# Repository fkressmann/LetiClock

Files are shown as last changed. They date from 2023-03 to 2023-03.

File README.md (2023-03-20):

# LetiClock
German word clock implementation with some custom features. Maybe built for someone I like very much and maybe this 
explains the weird project name, maybe.

A demo of the full functionality (including OTA update) can be found 
[here on OneDrive](https://1drv.ms/v/s!ApTlIRJaAWv_hIA3SK2NMBU7i5G7rw?e=YNfXNx)

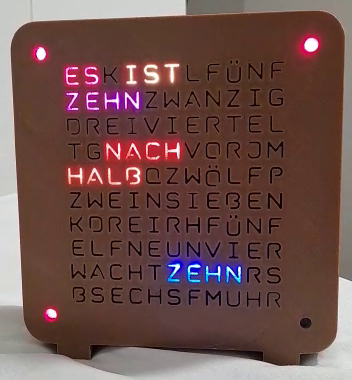
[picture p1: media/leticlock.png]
LetiClock


## Features
### Adaptive brightness with LDR
I put a LDR into the back side of the case and a voltage divider to read the environments' brightness.
Then an exponential function is used to account for the non-linearity of the sensor. The values were just the result of 
some experimentation.

### NTP sync
Time is synced with a given NTP server using the native time library.

### HTTP OTA Updates (incl simple PHP update server script and Dockerfile)
As the device is deployed in the field, I don't have physical access to it.
To still be able to push new features and fix bugs, it connects every few minutes to a predefined endpoint to check 
if a new firmware version is available.

The connection is encrypted over HTTPs, the certificate is self-signed and the fingerprint is part of the software 
configuration. The encryption was mainly done to encrypt MQTT traffic, and it would be pointless to maintain two 
WiFiClients.

The firmware server is a simple PHP script deployed in a docker container behind [Nginx Proxy Manager](https://nginxproxymanager.com/)
which handles the encryption. A small Python script is used to parse the version out of the C++ files and modify the PHP script.
Run configurations in IntelliJ (see .idea directory) are used to build the firmware, execute the Python script, build a container and deploy it
to my docker host. And yes, this can be massively improved, but it's more than sufficient for my needs.

### MQTT client for receiving scrolling text messages
C'mon on, that's fckin cool :D

Reasons for choosing MQTT were that 
- I already have a server that I maintain for my smart home devices 
- I didn't want to modify some firewalls in the place where it might be installed
- I wanted a way to send messages from whatever device

Implementation wise the interesting part is how messages are reliably delivered.
The secret there are the [QoS levels](https://www.hivemq.com/blog/mqtt-essentials-part-6-mqtt-quality-of-service-levels/)
of MQTT. 
The following requirements were set:
- A message should arrive even when network connection of the clock is bad
- A message should play until a user interaction
- A messages should not get lost because of a busy resource

I wanted to offload as much as I can to the broker. QoS level 1 helps a lot there,
as it guarantees a message to be delivered 'at least once'. So once my client first connects with QoS 1 and subscribes to a topic,
the broker will cache messages if the client goes offline / loses its connection.

And this can be used for queueing, too. Instead of keeping messages in memory, we query them one by one from the broker.
Once a message is received, the client disconnects from the broker and plays the
message until the user presses one of the two button on the backside. Further messages send during this time will be chaced
by the broker. Once the button was pressed, the clock goes back to normal mode, connects to the broker again and possibly receives the next message.
This goes on until all messages are processed.

### 3d print
As I could get my hands neither on 90 LED/m nor a 96 LED/m WS2812b, I went with a [100 LED/m WS2812 ECO](https://www.amazon.de/gp/product/B088JZCBDR) 
and scaled down the 90 LED/m 3D files X and Y axis to 90% in Cura. This worked out absolutely fine!

### Push button WiFi configuration
I figured out that WiFiManager opens the config portal in case it cannot connect to the last stored WiFi within a 
defined period of time. This is for the clocks use case unfortunate cause it's not often changing WiFi but used with 
flasky connections. So in the beginning it switched very often automatically to config mode.

To fix this, the config AP is activated by pressing both button on the back simultaneously. Otherwise, it will just indefinitely
try to connect to the last saved WiFi AP. This works perfect in the desired environment.

# Props
## Idea
- [3D Design | ingrimsch | WordClock 12h](https://www.thingiverse.com/thing:2130830)
- [Initial idea for the SW | mirohero | german word clock](https://github.com/mirohero/german-word-clock)
## Libraries
- [Scrolling Text lib | Aaron Liddiment | LEDMatrix / LEDText](https://github.com/AaronLiddiment)
- [FastLED | FastLED](https://github.com/FastLED/FastLED)
- [tzapu | WiFiManager](https://github.com/tzapu/WiFiManager)
- [knolleary | PubSubClient](https://github.com/knolleary/pubsubclient)

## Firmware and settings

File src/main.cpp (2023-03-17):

#include <Arduino.h>
#include <FastLED.h>
#include <LEDMatrix.h>
#include <LEDText.h>
#include <FontMatrise.h>
#include <time.h>
#include "ESP8266httpUpdate.h"
#include <DNSServer.h>
#include <WiFiManager.h>
#include <PubSubClient.h>
#include <credentials.h>

#define MY_NTP_SERVER "pool.ntp.org"
#define MY_TZ "CET-1CEST,M3.5.0/02,M10.5.0/03" // Settings for middle european time

#define VERSION     "LetiClock-v19"
#define LED_PIN     D3
#define LDR         A0
#define BUTTON_L    D1
#define BUTTON_R    D2
#define LED_TYPE    WS2812
#define COLOR_ORDER GRB

const String prefix = MQTT_PREFIX;
const char *topicMessage = "message";
const char *topicLog = "log";

void reconnectMqtt(boolean log);

void doBusiness();

struct {
    bool available = false;
    int length;
    char buffer[256];
} mqttMessage;

WiFiClientSecure espClient;
PubSubClient mqttClient(espClient);

cLEDMatrix<11, -10, HORIZONTAL_ZIGZAG_MATRIX> ledMatrix;
cLEDText ScrollingMsg;

int currentMinute, currentHour;
int previousMinute = 100; // Init with some insane value to trigger update on boot
const double E = 2.71828;
time_t now;
tm tm;
bool buttonL, buttonR = false;
bool outputEnabled = true;

struct WORD {
    int start;
    int length;
};

WORD W_ES = {0, 2};
WORD W_IST = {3, 3};
WORD W_M_FUENF = {7, 4};
WORD W_M_ZEHN = {18, 4};
WORD W_M_ZWANZIG = {11, 7};
WORD W_DREIVIERTEL = {22, 11};
WORD W_VIERTEL = {26, 7};
WORD W_NACH = {38, 4};
WORD W_VOR = {35, 3};
WORD W_HALB = {44, 4};
WORD W_S_ZWOELF = {49, 5};
WORD W_S_ZWEI = {62, 4};
WORD W_S_EIN = {61, 3};
WORD W_S_EINS = {60, 4};
WORD W_S_SIEBEN = {55, 6};
WORD W_S_DREI = {67, 4};
WORD W_S_FUENF = {73, 4};
WORD W_S_ELF = {85, 3};
WORD W_S_NEUN = {81, 4};
WORD W_S_VIER = {77, 4};
WORD W_S_ACHT = {89, 4};
WORD W_S_ZEHN = {93, 4};
WORD W_S_SECHS = {104, 5};
WORD W_UHR = {99, 3};

// first byte encodes array length, rest the LEDs positions
const int info_WIFI[] = {4, 16, 25, 53, 59};
const int info_MQTT[] = {4, 43, 33, 48, 92};
const int info_MQT[] = {3, 43, 33,
                        48}; // Used to display 'MQT' while displaying the time as this does not use any letters that time would use
const int info_UPDATE[] = {6, 8, 54, 67, 89, 92, 94};
const int info_DONE[] = {4, 22, 36, 61, 69};
const int info_ERROR[] = {5, 0, 23, 29, 36, 68};
const int info_CONNECT[] = {7, 39, 36, 55, 61, 69, 90, 92};
const int info_TIME[] = {4, 5, 12, 33, 56};

char serialBuffer[4] = {};

bool wasButtonPressed() {
    return buttonL || buttonR;
}

void sendData(String subtopic, const char *data, bool retained) {
    subtopic = prefix + subtopic;
    Serial.printf("Sending %s via MQTT to topic %s\n", data, subtopic.c_str());
    mqttClient.publish(subtopic.c_str(), data, retained);
}

void sendData(String subtopic, String data, bool retained) {
    sendData(subtopic, (String(asctime(&tm)) + data).c_str(), retained);
}

void adjustBrightness() {
    int value = analogRead(LDR);
    // Exponential scaling of 10bit analog input to 8bit LED brightness
    int brightness = max(2, (int) (pow(E, 0.0072195 * value) * 0.149831));
    Serial.printf("Brightness analog / digital: %d / %d \n", value, brightness);
    FastLED.setBrightness(brightness);
    FastLED.show();
}

uint8_t randomColor() {
    return random(0, 256);
}

void setLed(uint8_t i, uint8_t h, uint8_t s, uint8_t v) {
    Serial.printf("Setting LED %d (H%d S%d V%d)\n", i, h, s, v);
    ledMatrix(i).setHSV(h, s, v);
}

void setLed(uint8_t i, uint8_t color) {
    setLed(i, color, 255, 255);
}

void showInfo(const int *info) {
    FastLED.clear(true);
    int length = info[0];
    int color = randomColor();
    for (int i = 1; i <= length; i++) {
        setLed(info[i], color);
    }
    FastLED.show();
    FastLED.show();
}

void setTranslucentMqt(uint8_t brightness) {
    Serial.println("Setting translucent MQT");
    int length = info_MQT[0];
    int color = randomColor();
    for (int i = 1; i <= length; i++) {
        setLed(info_MQT[i], color, 255, brightness);
    }
    FastLED.show();
    FastLED.show();
}

void setTranslucentMqt() {
    setTranslucentMqt(255);
    // ToDo: Change this to a lower brightness as soon as using a Async MQTT lib
    // at the moment, mqttClint.connect() is blocking for up to 5 sec which prevents FastLED from dithering
    // and thus MQT might not be visible during connection when master brightness is low
}

void clearTranslucentMqt() {
    setTranslucentMqt(0);
}

void setWord(WORD word) {
    int color = randomColor();
    for (int i = word.start; i < word.start + word.length; i++) {
        setLed(i, color);
    }
}

void prepareMessage(char *payload, unsigned int length) {
    mqttMessage.buffer[0] = EFFECT_SCROLL_LEFT[0];
    mqttMessage.buffer[1] = ' '; // Two spaces in the beginning to slide message into canvas
    mqttMessage.buffer[2] = ' ';
    strncpy(mqttMessage.buffer + 3, payload, length);
    mqttMessage.buffer[length + 3] = ' '; // And one to slide it out
    mqttMessage.buffer[length + 4] = '\0'; //End string here cause it's a C string
    mqttMessage.available = true;
    mqttMessage.length = length + 4;
}

void mqttCallback(char *topic, byte *payload, unsigned int length) {
    char *slashPointer = strrchr(topic, '/');
    if (strcmp(slashPointer + 1, topicMessage) == 0) {
        prepareMessage((char *) payload, length);
    }
}

void handleMinutes() {
    setWord(W_ES);
    setWord(W_IST);
    int minutes = currentMinute % 5;
    int color = randomColor();
    switch (minutes) {
        case 4:
            setLed(111, color);
        case 3:
            setLed(110, color);
        case 2:
            setLed(112, color);
        case 1:
            setLed(113, color);
    }

    if (currentMinute >= 0 && currentMinute < 5) {
        setWord(W_UHR);
        return;
    }
    if (currentMinute >= 5 && currentMinute < 10) {
        setWord(W_M_FUENF);
        setWord(W_NACH);
        return;
    }
    if (currentMinute >= 10 && currentMinute < 15) {
        setWord(W_M_ZEHN);
        setWord(W_NACH);
        return;
    }
    if (currentMinute >= 15 && currentMinute < 20) {
        if (random(0, 2) == 0) {
            setWord(W_VIERTEL);
            setWord(W_NACH);
        } else {
            setWord(W_VIERTEL);
            currentHour++;
        }
        return;
    }
    if (currentMinute >= 20 && currentMinute < 25) {
        if (random(0, 2) == 0) {
            setWord(W_M_ZWANZIG);
            setWord(W_NACH);
        } else {
            setWord(W_M_ZEHN);
            setWord(W_VOR);
            setWord(W_HALB);
            currentHour++;
        }
        return;
    }
    if (currentMinute >= 25 && currentMinute < 30) {
        setWord(W_M_FUENF);
        setWord(W_VOR);
        setWord(W_HALB);
        return;
    }
    if (currentMinute >= 30 && currentMinute < 35) {
        setWord(W_HALB);
        return;
    }
    if (currentMinute >= 35 && currentMinute < 40) {
        setWord(W_M_FUENF);
        setWord(W_NACH);
        setWord(W_HALB);
        return;
    }
    if (currentMinute >= 40 && currentMinute < 45) {
        if (random(0, 2) == 0) {
            setWord(W_M_ZWANZIG);
            setWord(W_VOR);
        } else {
            setWord(W_M_ZEHN);
            setWord(W_NACH);
            setWord(W_HALB);
        }
        return;
    }
    if (currentMinute >= 45 && currentMinute < 50) {
        if (random(0, 2) == 0) {
            setWord(W_VIERTEL);
            setWord(W_VOR);
        } else {
            setWord(W_DREIVIERTEL);
        }
        return;
    }
    if (currentMinute >= 50 && currentMinute < 55) {
        setWord(W_M_ZEHN);
        setWord(W_VOR);
        return;
    }
    if (currentMinute >= 55) {
        setWord(W_M_FUENF);
        setWord(W_VOR);
        return;
    }
}

void handleHours() {
    switch (currentHour) {
        case 1:
            if (currentMinute >= 0 && currentMinute < 5) {
                setWord(W_S_EIN);
            } else {
                setWord(W_S_EINS);
            }
            break;
        case 2:
            setWord(W_S_ZWEI);
            break;
        case 3:
            setWord(W_S_DREI);
            break;
        case 4:
            setWord(W_S_VIER);
            break;
        case 5:
            setWord(W_S_FUENF);
            break;
        case 6:
            setWord(W_S_SECHS);
            break;
        case 7:
            setWord(W_S_SIEBEN);
            break;
        case 8:
            setWord(W_S_ACHT);
            break;
        case 9:
            setWord(W_S_NEUN);
            break;
        case 10:
            setWord(W_S_ZEHN);
            break;
        case 11:
            setWord(W_S_ELF);
            break;
        case 12:
        case 0:
            setWord(W_S_ZWOELF);
            break;
    }
}

void renderClock() {
    currentHour = tm.tm_hour;
    currentMinute = tm.tm_min;
    FastLED.clear();
    handleMinutes();
    if (currentMinute >= 25) currentHour++;
    if (currentHour > 12) currentHour = currentHour - 12;
    handleHours();
    if (!mqttClient.connected()) setTranslucentMqt(); // Show MQT when connection is not established
    FastLED.show();
    FastLED.show();
}

void handleClock() {
    currentMinute = tm.tm_min;
    if (currentMinute != previousMinute) {
        renderClock();
        previousMinute = currentMinute;
    }
}

void showText(bool infinite) {
    sendData("ack", ": mes-rec", false);
    // Disconnect MQTT to
    // 1. not time-out cause message can run for long time
    // 2. not receive other messages while this is displayed, Broker will cache QOS1 for us
    bool wasMqttConnected = mqttClient.connected();
    if (wasMqttConnected) mqttClient.disconnect();
    FastLED.clearData();
    while (!buttonL && !buttonR) {
        ScrollingMsg.SetText((unsigned char *) mqttMessage.buffer, mqttMessage.length);
        while (!wasButtonPressed() && ScrollingMsg.UpdateText() != -1) {
            adjustBrightness();
            FastLED.delay(100);
        }
        if (!infinite) break;
    }
    buttonL = false; // Clear button press to not trigger unwanted actions in next handleButtons() run
    buttonR = false;
    if (wasMqttConnected) reconnectMqtt(false);
    mqttMessage.available = false;
    outputEnabled = true;
    if (infinite) renderClock(); // Directly trigger rendering of clock after running infinite message
}

void reconnectMqtt(bool log) {
    if (!mqttClient.connected()) {
        setTranslucentMqt();
        FastLED.show();
        Serial.println("Connecting to MQTT");
        if (log) showInfo(info_MQTT);
        if (mqttClient.connect(
                DEVICE_NAME,
                MQTT_USER,
                MQTT_PASSWORD,
                (prefix + "lwt").c_str(),
                0,
                true,
                "offline",
                false)
                ) {
            mqttClient.subscribe((prefix + topicMessage).c_str(), 1);
            if (log)
                sendData("lwt",
                         String(VERSION) + " connected",
                         true);
            clearTranslucentMqt();
            Serial.println("MQTT connected");
        } else {
            Serial.println("MQTT connection failed");
            FastLED.delay(1000);
        }
    }
}

void callbackUpdateStarted() {
    showInfo(info_UPDATE);
}

void callbackUpdateProgress(int current, int total) {
    int progress = ((float) current / (float) total) * 110;
    Serial.printf("Update current/total:progress %d / %d : %d\n", current, total, progress);
    setLed(progress, randomColor());
    FastLED.show();
    FastLED.show(); // Need this twice to be shown, no idea why
}

void callbackUpdateEnd() {
    showInfo(info_DONE);
    Serial.printf("Update done\n");
}

void callbackUpdateError(int error) {
    showInfo(info_ERROR);
    Serial.printf("OTA error: %d\n", error);
}

void update() {
    Serial.printf("Asking for update...\n");
    bool wasMqttConnected = mqttClient.connected();
    if (wasMqttConnected) mqttClient.disconnect();
    t_httpUpdate_return ret = ESPhttpUpdate.update(espClient, MQTT_SERVER, 443, "/server.php", VERSION);
    if (wasMqttConnected) reconnectMqtt(false);
    switch (ret) {
        case HTTP_UPDATE_FAILED:
            Serial.printf("%s\n", ESPhttpUpdate.getLastErrorString().c_str());
            sendData(topicLog, ESPhttpUpdate.getLastErrorString(), true);
            break;

        case HTTP_UPDATE_NO_UPDATES:
            Serial.printf("HTTP_UPDATE_NO_UPDATES\n");
            break;

        case HTTP_UPDATE_OK:
            Serial.printf("HTTP_UPDATE_OK\n");
            break;
    }
}

void IRAM_ATTR isrButtonL() {
    buttonL = true;
}

void IRAM_ATTR isrButtonR() {
    buttonR = true;
}

void updateTime() {
    time(&now);                       // read the current time
    localtime_r(&now, &tm);           // update the structure tm with the current time
}

void handleButtons() {
    // Start config portal only if both buttons pressed
    if (buttonL && buttonR) {
        Serial.printf("Start config portal\n");
        showInfo(info_CONNECT);
        WiFiManager wifiManager;
        wifiManager.startConfigPortal("LetiClock", "ThisIsChildish:D");
        Serial.printf("Config finished: %s: %s \n", WiFi.SSID().c_str(), WiFi.psk().c_str());
    } else if (buttonL) {
        if (outputEnabled) {
            // Disable output
            Serial.println("Disabling output");
            FastLED.clear(true);
            outputEnabled = false;
        } else {
            // Enable output
            Serial.println("Enabling output");
            outputEnabled = true;
            renderClock(); // Directly trigger rendering of clock
        }
    }
    buttonL = false;
    buttonR = false;
}

void handleSerialInput() {
    if (Serial.available()) {
        int count = Serial.readBytesUntil('\n', serialBuffer, 4);
        Serial.printf("Received serial: %s \n", serialBuffer);
        if (count > 1) {
            int ledToLightUp = atoi(serialBuffer);
            setLed(ledToLightUp, randomColor());
            Serial.printf("Lighting up LED %d \n", ledToLightUp);
        } else if (count == 1) {
            FastLED.clear(true);
            Serial.println("Clearing LED data");
        }
    }
}

// To be called in all kinds of loop actions without MQTT
void doBusiness() {
    if (outputEnabled) adjustBrightness();
    FastLED.show();
    handleButtons();
    handleSerialInput();
    FastLED.show();
    yield();
}

void setup() {
    Serial.begin(115200);
    // Important to attach interrupts before going into WiFi.isConnected() loop!
    pinMode(BUTTON_L, INPUT_PULLUP);
    attachInterrupt(digitalPinToInterrupt(BUTTON_L), isrButtonL, FALLING);
    pinMode(BUTTON_R, INPUT_PULLUP);
    attachInterrupt(digitalPinToInterrupt(BUTTON_R), isrButtonR, FALLING);

    FastLED.addLeds<LED_TYPE, LED_PIN, COLOR_ORDER>(ledMatrix[0], ledMatrix.Size() + 4).setCorrection(TypicalLEDStrip);
    adjustBrightness();

    Serial.printf("Firmware version: %s\n", VERSION);

    showInfo(info_WIFI);
    Serial.printf("Connecting to WiFi: %s: %s \n", WiFi.SSID().c_str(), WiFi.psk().c_str());
    WiFi.persistent(true);
    WiFi.begin();
    while (!WiFi.isConnected()) {
        delay(500);
        doBusiness();
        Serial.print(".");
    }
    Serial.println();

    espClient.setFingerprint(SSL_FINGERPRINT);

    ESPhttpUpdate.onStart(callbackUpdateStarted);
    ESPhttpUpdate.onProgress(callbackUpdateProgress);
    ESPhttpUpdate.onEnd(callbackUpdateEnd);
    ESPhttpUpdate.onError(callbackUpdateError);
    update();

    showInfo(info_TIME);
    configTime(MY_TZ, MY_NTP_SERVER);
    // Wait for valid time sync (not year 1970 anymore)
    Serial.println("Waiting for valid time sync...");
    do {
        doBusiness();
        delay(100); // Allow some time for getting a sync
        updateTime();
        Serial.printf("Year is: %d\n", tm.tm_year + 1900);
    } while (tm.tm_year < 100); // Years before 2000 -> indicates an issue
    Serial.printf("Got valid sync: %s\n", asctime(&tm));

    mqttClient.setServer(MQTT_SERVER, MQTT_PORT);
    mqttClient.setCallback(mqttCallback);

    ScrollingMsg.SetFont(MatriseFontData);
    ScrollingMsg.Init(&ledMatrix, ledMatrix.Width(), ScrollingMsg.FontHeight() + 1, 0, 0);
    ScrollingMsg.SetTextColrOptions(COLR_GRAD_AH, 0x00, 0xff, 0x00, 0x00, 0x00, 0xff);

    prepareMessage(VERSION, sizeof(VERSION));
    showText(false);

    reconnectMqtt(true);
}

void loop() {
    FastLED.show();
    reconnectMqtt(false);
    FastLED.show();
    updateTime();
    FastLED.show();
    doBusiness();
    FastLED.show();
    if (outputEnabled) handleClock();
    FastLED.show();
    mqttClient.loop();
    if (millis() % 1000 < 2) update();
    FastLED.delay(1000);
    if (mqttMessage.available) showText(true);
}

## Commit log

2022-11-29 Change 5min intervals for minute LEDs
2022-11-29 MQTT messages: avoid String(), repeat forever, use QOS (queue messages on broker using disconnect), stop scrolling text with buttons
    [main.cpp]
2022-11-29 corrections in showWord(), version etc
    [main.cpp]
2022-11-29 Fix EINS not being cleared properly
    [main.cpp]
2022-11-29 Change order of commands to still show time when MQTT connection fails
    [main.cpp]
2022-11-29 Adjust brightness while playing text, OTA callbacks, ack MQTT texts, fix missing letter on showWord()
    [main.cpp]
2022-11-29 Pong MQTT messages, fix DREIVIERTEL not being reverted, increase version
    [main.cpp]
2022-12-05 Clear LED data on every clock update automatically (& remove manual clearing)
2023-01-07 WiFi Portal only on button press to not enter config mode when on bad Wifi
2023-01-10 Don't interrupt time display with MQTT when checking for updates
2023-01-10 Fix update progress calculation, use gradient color for scrolling text, indicate config portal with 'CONNECT'
    [main.cpp]
2023-01-15 Fritzing Sketch of Controller board
    [ControllerBoard.fzz]
2023-01-16 Remove debugging mode, make Serial prints persistent. No need to have those only in debug mode as the sketch has no real-time needs. Makes debugging easier in the long run...
2023-01-18 V17: Fixed not able to open config portal while WiFi connect issue, fixed wait for time sync condition
    [main.cpp]
2023-02-07 Fix info words, add some more delay to WiFi connect loop for easier button handling
    [main.cpp]
2023-03-15 Use buttonL for toggling output on and off
2023-03-17 Fix clock rendering after boot message
    [main.cpp]
2023-03-17 Add README.md, prepare for GitHub publish
    [ControllerBoard.fzz]
